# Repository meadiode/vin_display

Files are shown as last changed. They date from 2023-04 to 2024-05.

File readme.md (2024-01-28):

# Vintage display module

A series of RP2040 based display modules for 3d-printers using dot-matrix, or 16-segment vintage display ICs.
Intended to be used with [Klipper firmware](https://www.klipper3d.org/).

Currently the following displays were built and tested:

## VinDisplay mdl2416c_x10
Display module features ten MDL2416C which are 4-character 16-segment LED displays.
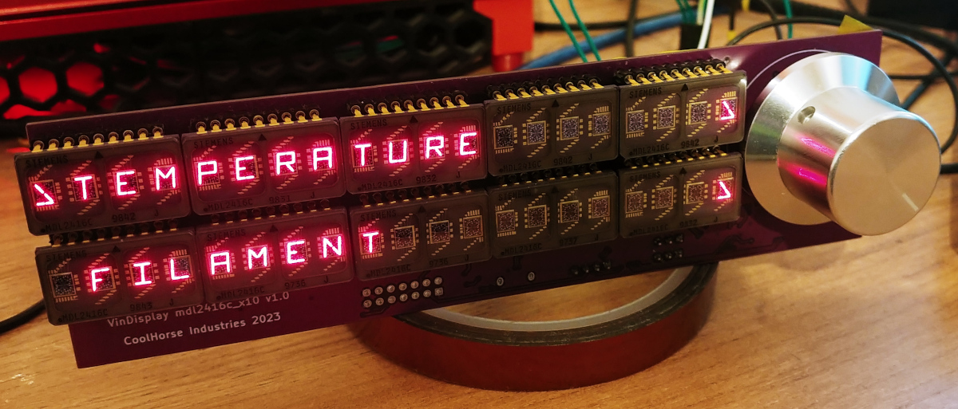
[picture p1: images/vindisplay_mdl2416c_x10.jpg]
VinDisplay mdl2416c_x10


## VinDisplay hdsp2112_x6
Display module features six HDSP-2112 which are 8-character 5x7 LED dot-matrix displays.
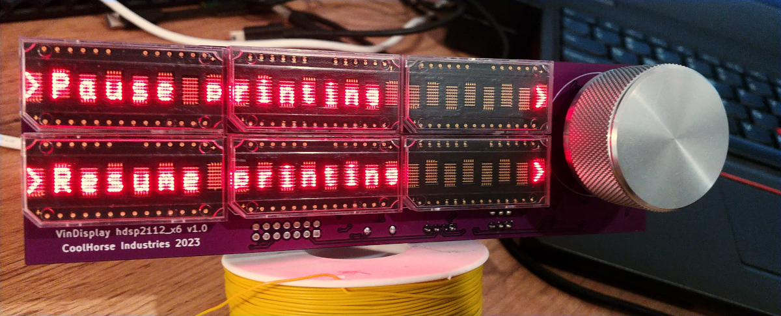
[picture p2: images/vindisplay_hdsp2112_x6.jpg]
VinDisplay hdsp2112_x6


## DemoBoard 1
Simplistic demo-board to evaluate MDL2416C(16-segment LED display), 8 of them are driven by a pico_w. The board just displays current time and date and also prints custom message through a web-interface.
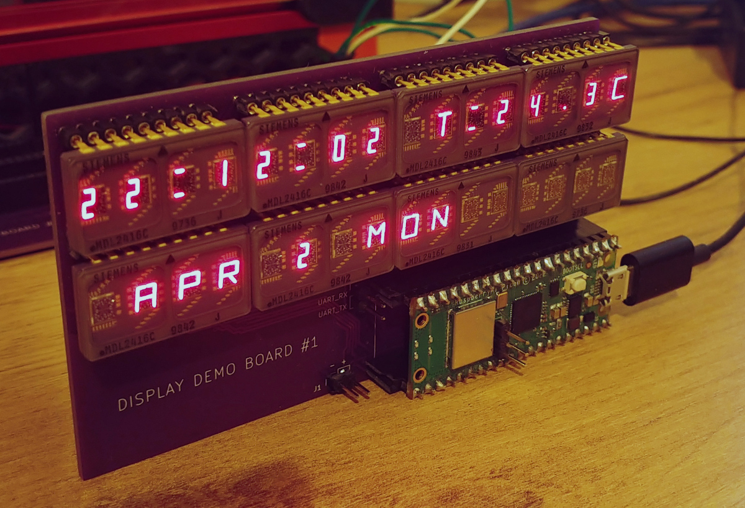
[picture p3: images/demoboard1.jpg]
DemoBoard1


## Building Firmware

### Prerequisites 

Generally, refer to the official [Getting started guide](https://datasheets.raspberrypi.com/pico/getting-started-with-pico.pdf)

You'll need to have:

- ARM embedded gcc toolchain
- GDB (gdb-multiarch)
- Pico SDK
- Pico probe
- FreeRTOS
- Pico OpenOCD

The following environment constants should be defined:
```
PICO_SDK_PATH=/* Path to the root of pico-sdk directory */
FREERTOS_KERNEL_PATH=/* Path to the root of FreeRTOS kernel directory */
```

### Configuring and building

```
cd src
mkdir build
cd build
cmake -DCMAKE_BUILD_TYPE=Debug ..

make
```

### Running and debugging

Connect the picoprobe to the target pico_w board according to the "getting started guide", then run the following:

```
cd [Pico OpenOCD source directory]
sudo src/openocd -f interface/picoprobe.cfg -f target/rp2040.cfg -s tcl
```
It should start a GDB server on the default port 3333.

To flash and run/debug the firmware navigate to the project's directory and run the following: 
```
cd build
gdb-multiarch ./<binary name>.elf
```
Once GDB started:
```
target remote :3333
load
monitor init reset
cont
```

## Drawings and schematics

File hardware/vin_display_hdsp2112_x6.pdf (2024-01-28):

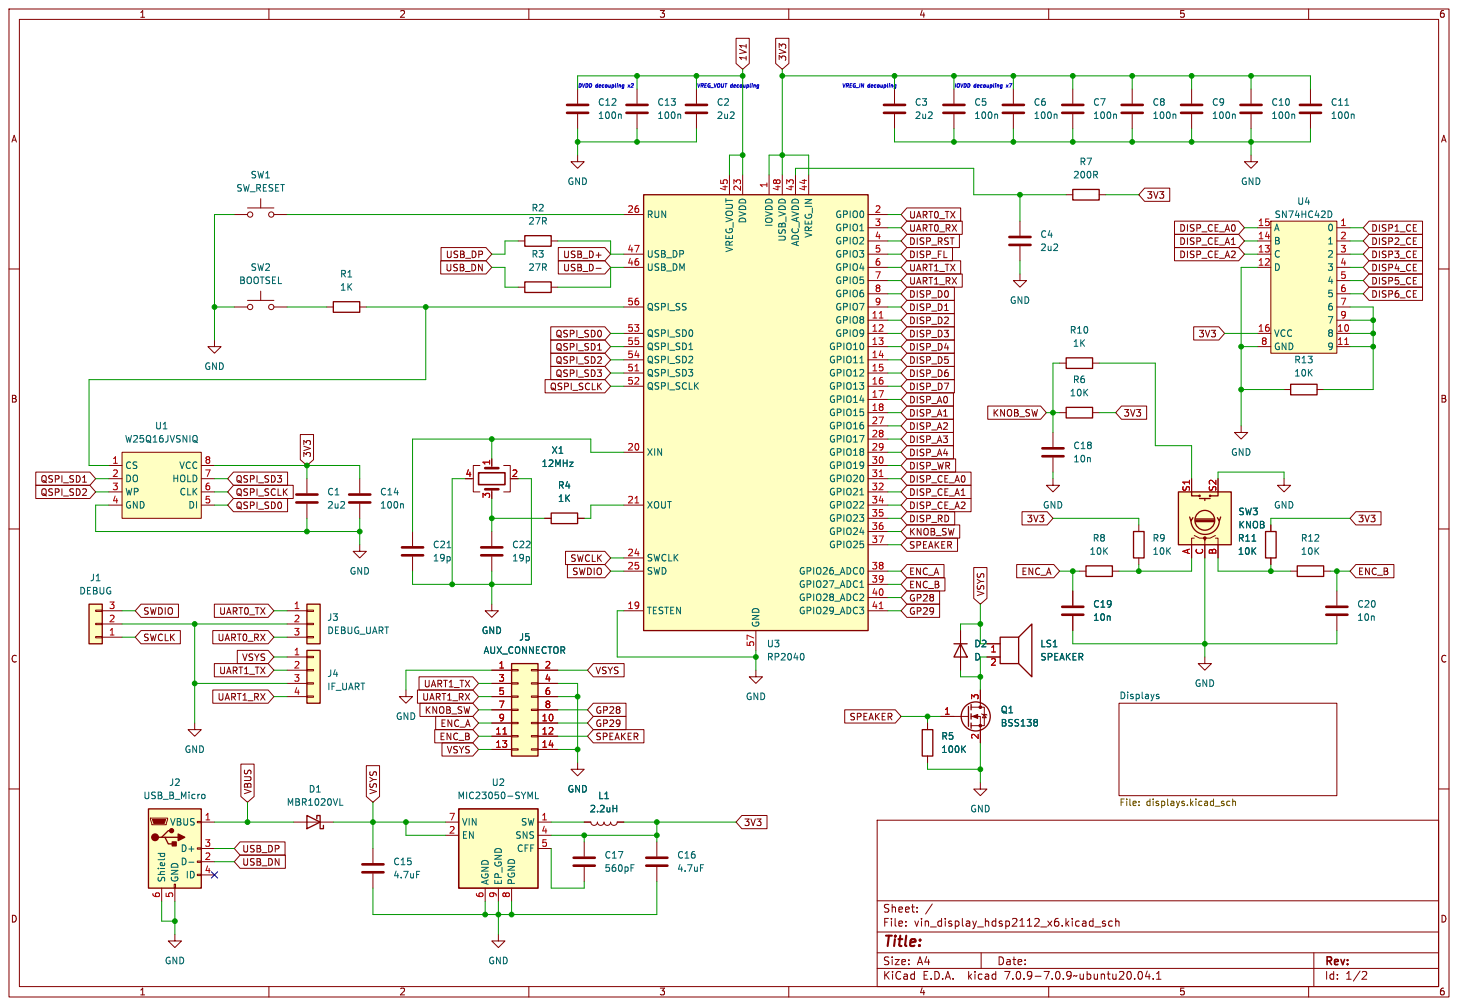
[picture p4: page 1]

1 GPIO8 11 GPIO9 12 GPIO10 13 GPIO11 14 GPIO12 15 GPIO13 16 GPIO14 17 GPIO15 18 TESTEN 19 GPIO0 2 XIN 20 XOUT 21 DVDD 23 SWCLK 24 SWD 25 RUN 26 GPIO16 27 GPIO17 28 GPIO18 29 GPIO1 3 GPIO19 30 GPIO20 31 GPIO21 32 GPIO22 34 GPIO23 35 GPIO24 36 GPIO25 37 GPIO26_ADC0 38 GPIO27_ADC1 39 GPIO2 4 GPIO28_ADC2 40 GPIO29_ADC3 41 ADC_AVDD 43 VREG_IN 44 VREG_VOUT 45 USB_DM 46 USB_DP 47 USB_VDD 48 GPIO3 5 QSPI_SD3 51 QSPI_SCLK 52 QSPI_SD0 53 QSPI_SD2 54 QSPI_SD1 55 QSPI_SS 56 GND 57 GPIO4 6 GPIO5 7 GPIO6 8 GPIO7 9 U3 RP2040 GND GND GND

9 SW 1 EN 2 SNS 4 CFF 5 AGND

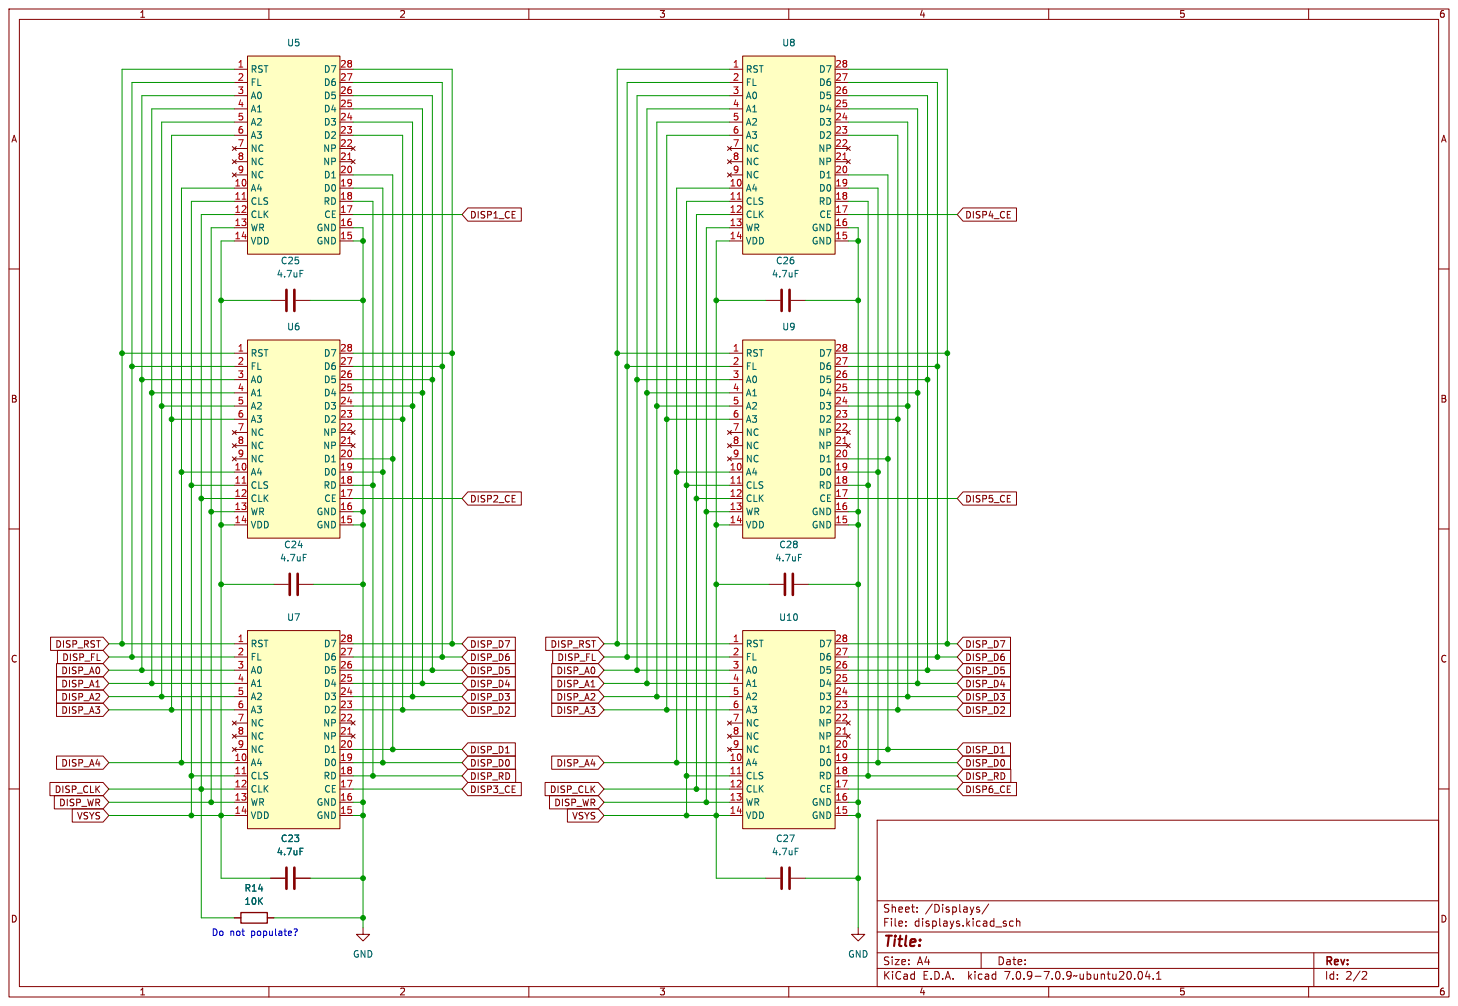
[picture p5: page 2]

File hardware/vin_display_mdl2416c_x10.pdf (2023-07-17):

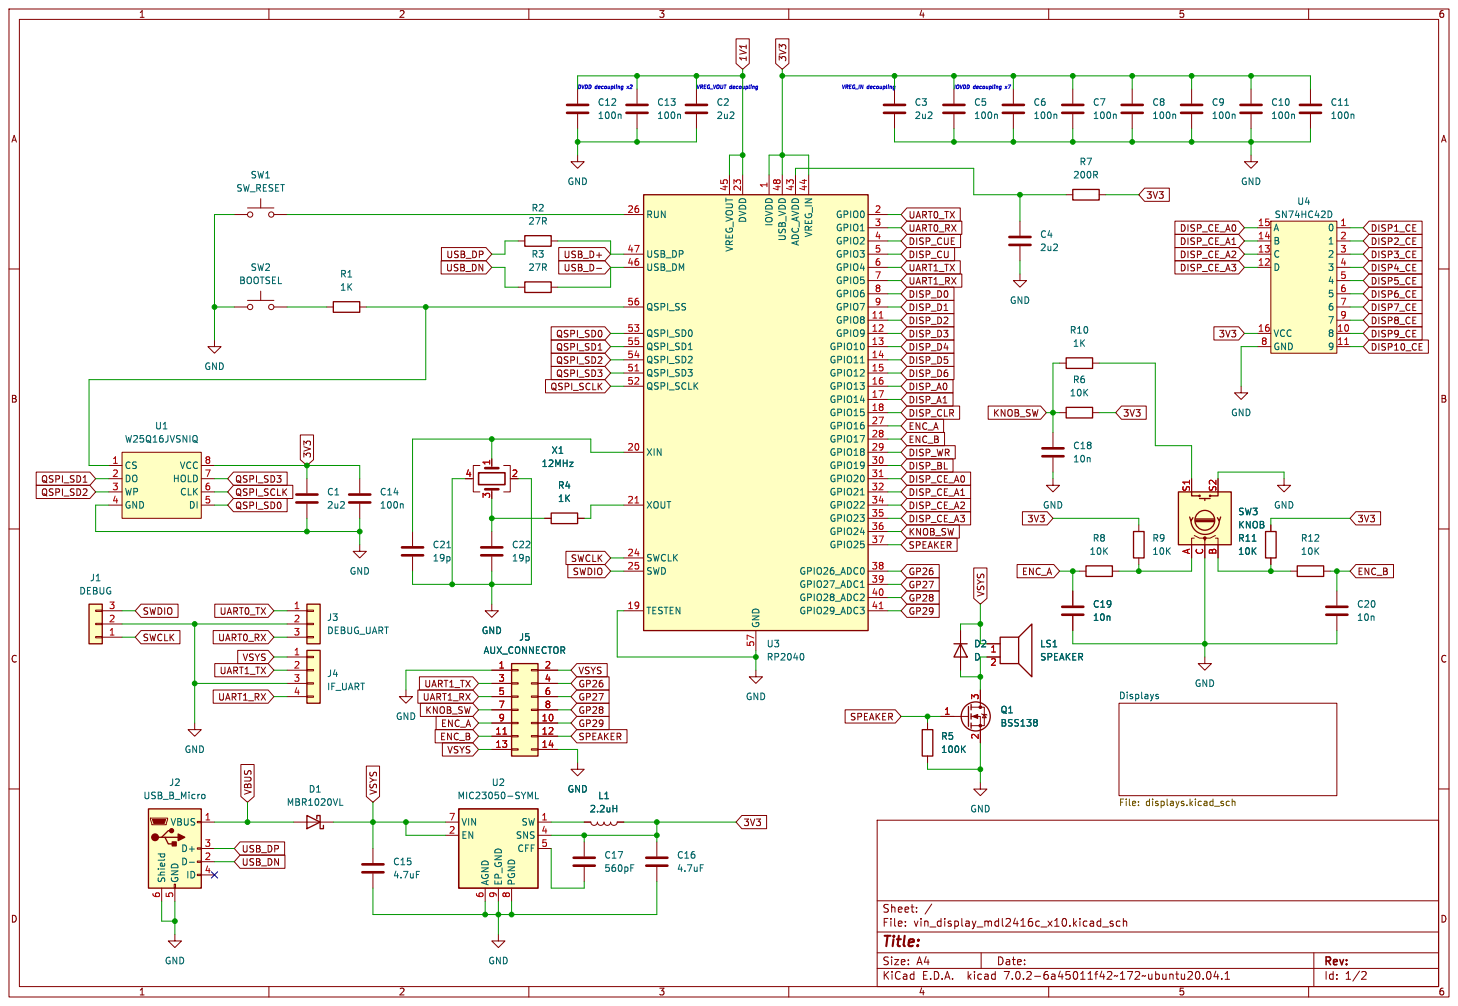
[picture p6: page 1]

1 GPIO8 11 GPIO9 12 GPIO10 13 GPIO11 14 GPIO12 15 GPIO13 16 GPIO14 17 GPIO15 18 TESTEN 19 GPIO0 2 XIN 20 XOUT 21 DVDD 23 SWCLK 24 SWD 25 RUN 26 GPIO16 27 GPIO17 28 GPIO18 29 GPIO1 3 GPIO19 30 GPIO20 31 GPIO21 32 GPIO22 34 GPIO23 35 GPIO24 36 GPIO25 37 GPIO26_ADC0 38 GPIO27_ADC1 39 GPIO2 4 GPIO28_ADC2 40 GPIO29_ADC3 41 ADC_AVDD 43 VREG_IN 44 VREG_VOUT 45 USB_DM 46 USB_DP 47 USB_VDD 48 GPIO3 5 QSPI_SD3 51 QSPI_SCLK 52 QSPI_SD0 53 QSPI_SD2 54 QSPI_SD1 55 QSPI_SS 56 GND 57 GPIO4 6 GPIO5 7 GPIO6 8 GPIO7 9 U3 RP2040 AC

9 SW 1 EN 2 SNS 4 CFF 5 AGND

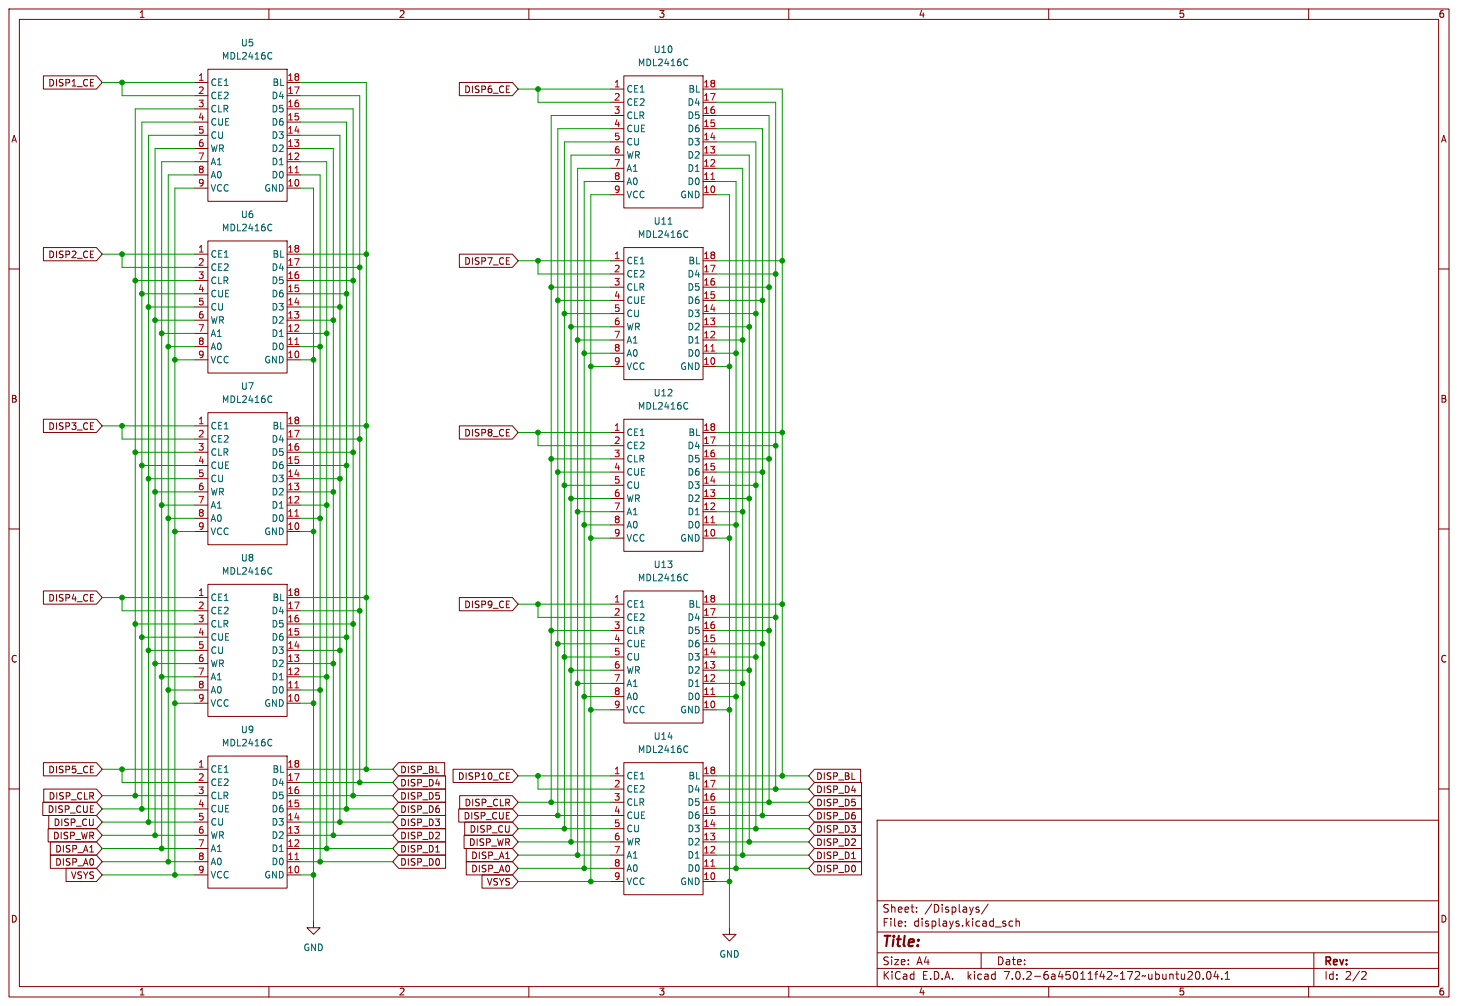
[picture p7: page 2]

Id: 2/2 Title: File: displays.kicad_sch Sheet: /Displays/

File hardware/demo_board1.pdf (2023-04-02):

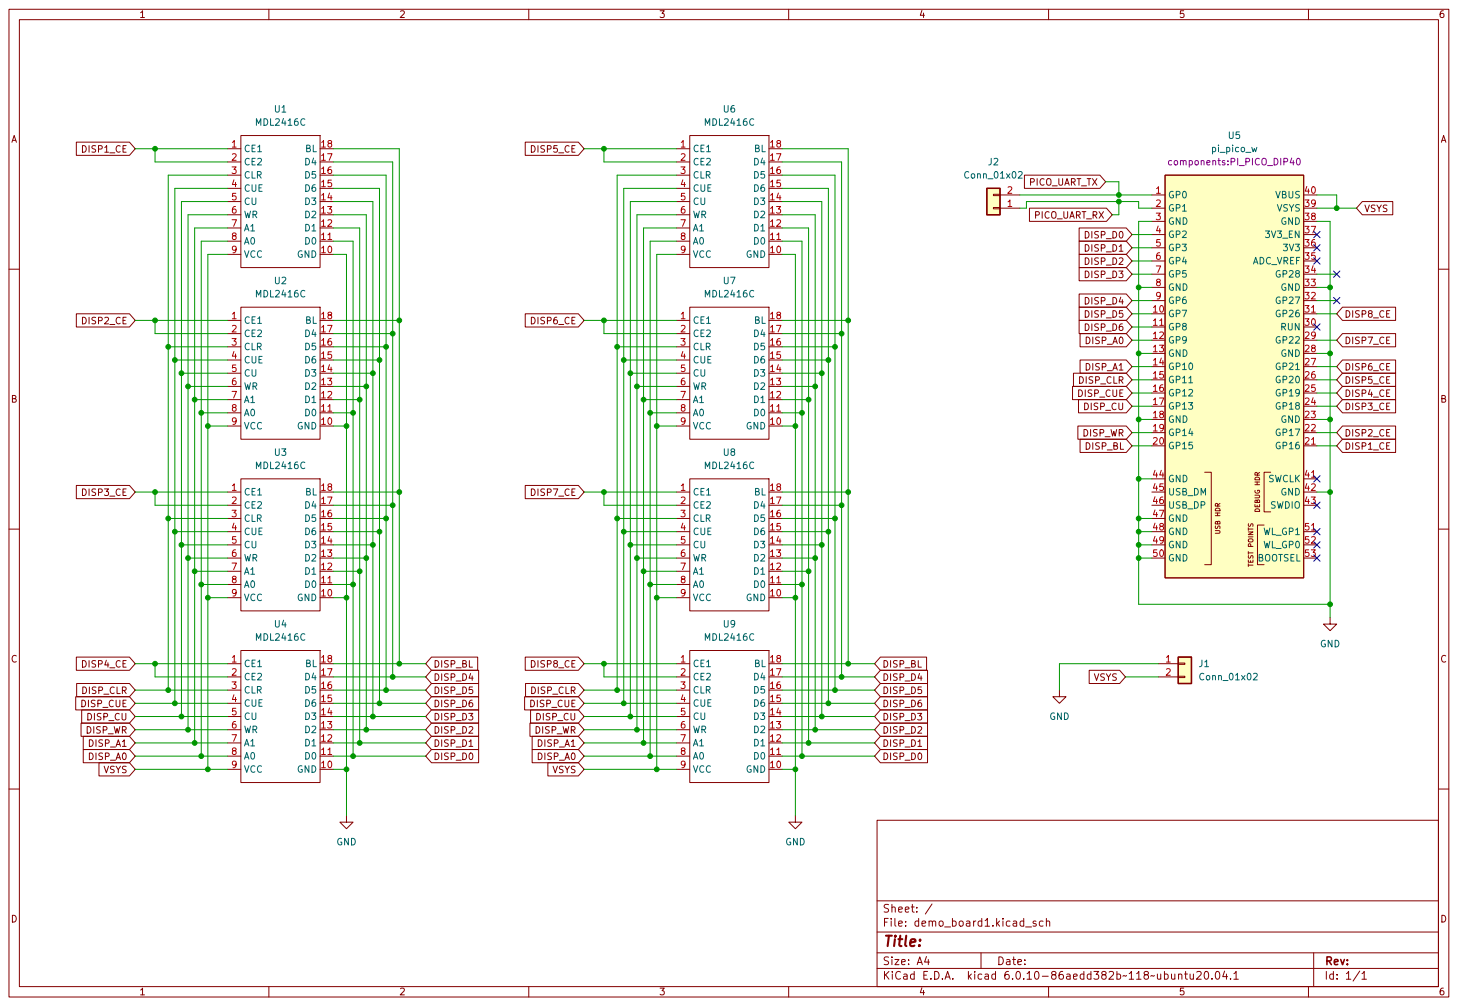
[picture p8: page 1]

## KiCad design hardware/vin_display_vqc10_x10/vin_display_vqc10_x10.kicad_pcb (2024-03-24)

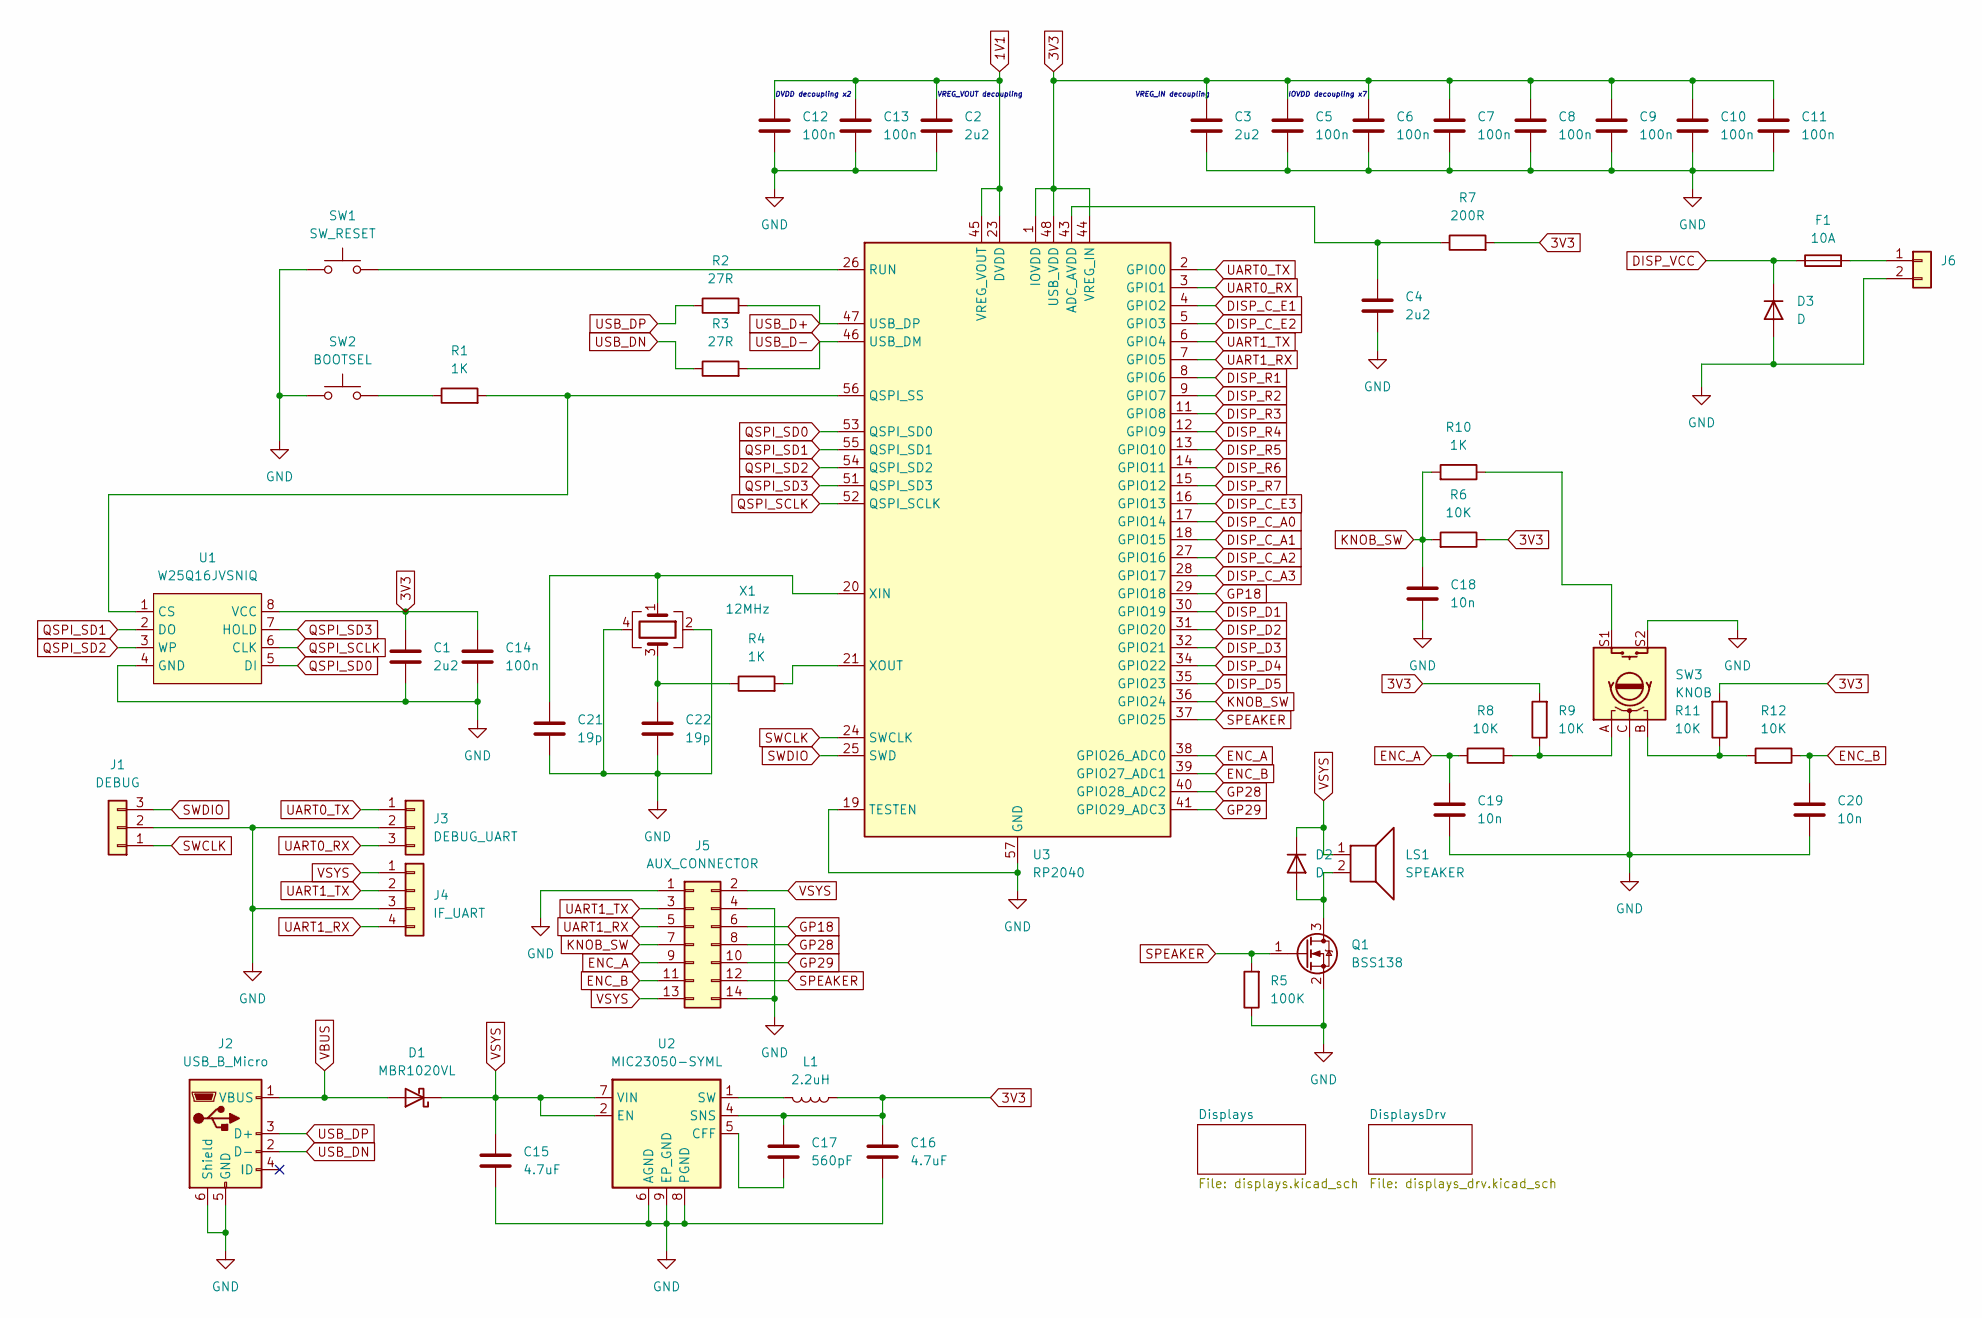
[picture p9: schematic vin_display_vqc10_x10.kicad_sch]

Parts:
C1, C2, C3, C4: 2u2; C_0603_1608Metric
C5, C6, C7, C8, C9, C10, C11, C12, C13, C14: 100n; C_0603_1608Metric
C15, C16: 4.7uF; C_0603_1608Metric
C17: 560pF; C_0603_1608Metric
C18, C19, C20: 10n; C_0603_1608Metric
C21, C22: 19p; C_0603_1608Metric
D1: MBR1020VL; D_SOD-123F
D2: D; D_SOD-123
D3: D; Diode_TO252
F1: 10A; Fuse_2410
J1: DEBUG; JST_EH_B3B-EH-A_1x03_P2.50mm_Vertical
J2: USB_B_Micro; GCT_USB3140
J3: DEBUG_UART; JST_EH_B3B-EH-A_1x03_P2.50mm_Vertical
J4: IF_UART; JST_EH_B4B-EH-A_1x04_P2.50mm_Vertical
J5: AUX_CONNECTOR; IDC-Header_2x07_P2.54mm_Vertical
J6: Conn_01x02; Conn_2x3_96
L1: 2.2uH; Inductor_0806
LS1: SPEAKER; BUZZER_CMT-8504
Q1: BSS138; SOT-23
R1, R4, R10: 1K; R_0603_1608Metric
R2, R3: 27R; R_0603_1608Metric
R5: 100K; R_0603_1608Metric
R6, R8, R9, R11, R12: 10K; R_0603_1608Metric
R7: 200R; R_0603_1608Metric
SW1: SW_RESET; TS18_TACTILE_SWITCH
SW2: BOOTSEL; TS18_TACTILE_SWITCH
SW3: KNOB; PEC11H_Encoder
U1: W25Q16JVSNIQ; SOIC8_150mil
U2: MIC23050-SYML; Micrel_MLF-8-1EP_2x2mm_P0.5mm_EP0.6x1.2mm
U3: RP2040; QFN-56-1EP_7x7mm_P0.4mm_EP3.2x3.2mm
X1: 12MHz; Crystal_SMD_Abracon_ABM8AIG-4Pin_3.2x2.5mm

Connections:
1V1: C2.1, C12.1, C13.1, U3.23 (DVDD), U3.45 (VREG_VOUT), U3.50 (DVDD)
3V3: C1.1, C3.1, C5.1, C6.1, C7.1, C8.1, C9.1, C10.1, C11.1, C14.1, C16.1, C17.1, L1.1, R6.1, R7.2, R9.2, R11.2, U1.8 (VCC), U2.4 (SNS), U3.1 (IOVDD), U3.10 (IOVDD), U3.22 (IOVDD), U3.33 (IOVDD), U3.42 (IOVDD), U3.44 (VREG_IN), U3.48 (USB_VDD), U3.49 (IOVDD); also elsewhere on the board
DISP_C_A0: U3.17 (GPIO14); also elsewhere on the board
DISP_C_A1: U3.18 (GPIO15); also elsewhere on the board
DISP_C_A2: U3.27 (GPIO16); also elsewhere on the board
DISP_C_A3: U3.28 (GPIO17); also elsewhere on the board
DISP_C_E1: U3.4 (GPIO2); also elsewhere on the board
DISP_C_E2: U3.5 (GPIO3); also elsewhere on the board
DISP_C_E3: U3.16 (GPIO13); also elsewhere on the board
DISP_D1: U3.30 (GPIO19); also elsewhere on the board
DISP_D2: U3.31 (GPIO20); also elsewhere on the board
DISP_D3: U3.32 (GPIO21); also elsewhere on the board
DISP_D4: U3.34 (GPIO22); also elsewhere on the board
DISP_D5: U3.35 (GPIO23); also elsewhere on the board
DISP_R1: U3.8 (GPIO6); also elsewhere on the board
DISP_R2: U3.9 (GPIO7); also elsewhere on the board
DISP_R3: U3.11 (GPIO8); also elsewhere on the board
DISP_R4: U3.12 (GPIO9); also elsewhere on the board
DISP_R5: U3.13 (GPIO10); also elsewhere on the board
DISP_R6: U3.14 (GPIO11); also elsewhere on the board
DISP_R7: U3.15 (GPIO12); also elsewhere on the board
DISP_VCC: D3.1 (K), F1.1; also elsewhere on the board
ENC_A: C19.1, J5.9, R8.1, U3.38 (GPIO26_ADC0)
ENC_B: C20.1, J5.11, R12.1, U3.39 (GPIO27_ADC1)
GND: C1.2, C2.2, C3.2, C4.2, C5.2, C6.2, C7.2, C8.2, C9.2, C10.2, C11.2, C12.2, C13.2, C14.2, C15.2, C16.2, C18.2, C19.2, C20.2, C21.2, C22.2, D3.2 (A), J1.2, J2.5 (GND), J2.6 (Shield), J3.2, J4.3, J5.1, J5.4, J5.14, J6.2, Q1.2 (S), R5.1, SW1.1, SW2.1, SW3.C, SW3.S2, U1.4 (GND), U2.6 (AGND), U2.8 (PGND), U2.9 (EP_GND), U3.19 (TESTEN), U3.57 (GND), X1.2, X1.4; also elsewhere on the board
GP18: J5.6, U3.29 (GPIO18)
GP28: J5.8, U3.40 (GPIO28_ADC2)
GP29: J5.10, U3.41 (GPIO29_ADC3)
KNOB_SW: C18.1, J5.7, R6.2, R10.2, U3.36 (GPIO24)
unnamed: C22.1, R4.1, X1.3
unnamed: D2.2 (A), LS1.2, Q1.3 (D)
unnamed: F1.2, J6.1
unnamed: R1.1, SW2.2
unnamed: R8.2, R9.1, SW3.A
unnamed: R10.1, SW3.S1
unnamed: R11.1, R12.2, SW3.B
unnamed: R1.2, U1.1 (CS), U3.56 (QSPI_SS)
unnamed: C17.2, U2.5 (CFF)
unnamed: L1.2, U2.1 (SW)
unnamed: C4.1, R7.1, U3.43 (ADC_AVDD)
unnamed: SW1.2, U3.26 (RUN)
unnamed: C21.1, U3.20 (XIN), X1.1
unnamed: R4.2, U3.21 (XOUT)
QSPI_SCLK: U1.6 (CLK), U3.52 (QSPI_SCLK)
QSPI_SD0: U1.5 (DI), U3.53 (QSPI_SD0)
QSPI_SD1: U1.2 (DO), U3.55 (QSPI_SD1)
QSPI_SD2: U1.3 (WP), U3.54 (QSPI_SD2)
QSPI_SD3: U1.7 (HOLD), U3.51 (QSPI_SD3)
SPEAKER: J5.12, Q1.1 (G), R5.2, U3.37 (GPIO25)
SWCLK: J1.1, U3.24 (SWCLK)
SWDIO: J1.3, U3.25 (SWD)
UART0_RX: J3.3, U3.3 (GPIO1)
UART0_TX: J3.1, U3.2 (GPIO0)
UART1_RX: J4.4, J5.5, U3.7 (GPIO5)
UART1_TX: J4.2, J5.3, U3.6 (GPIO4)
USB_D+: R2.2, U3.47 (USB_DP)
USB_D-: R3.2, U3.46 (USB_DM)
USB_DN: J2.2 (D-), R3.1
USB_DP: J2.3 (D+), R2.1
VBUS: D1.2 (A), J2.1 (VBUS)
VSYS: C15.1, D1.1 (K), D2.1 (K), J4.1, J5.2, J5.13, LS1.1, U2.2 (EN), U2.7 (VIN)

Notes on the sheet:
IOVDD decoupling x7
DVDD decoupling x2
VREG_IN decoupling
VREG_VOUT decoupling

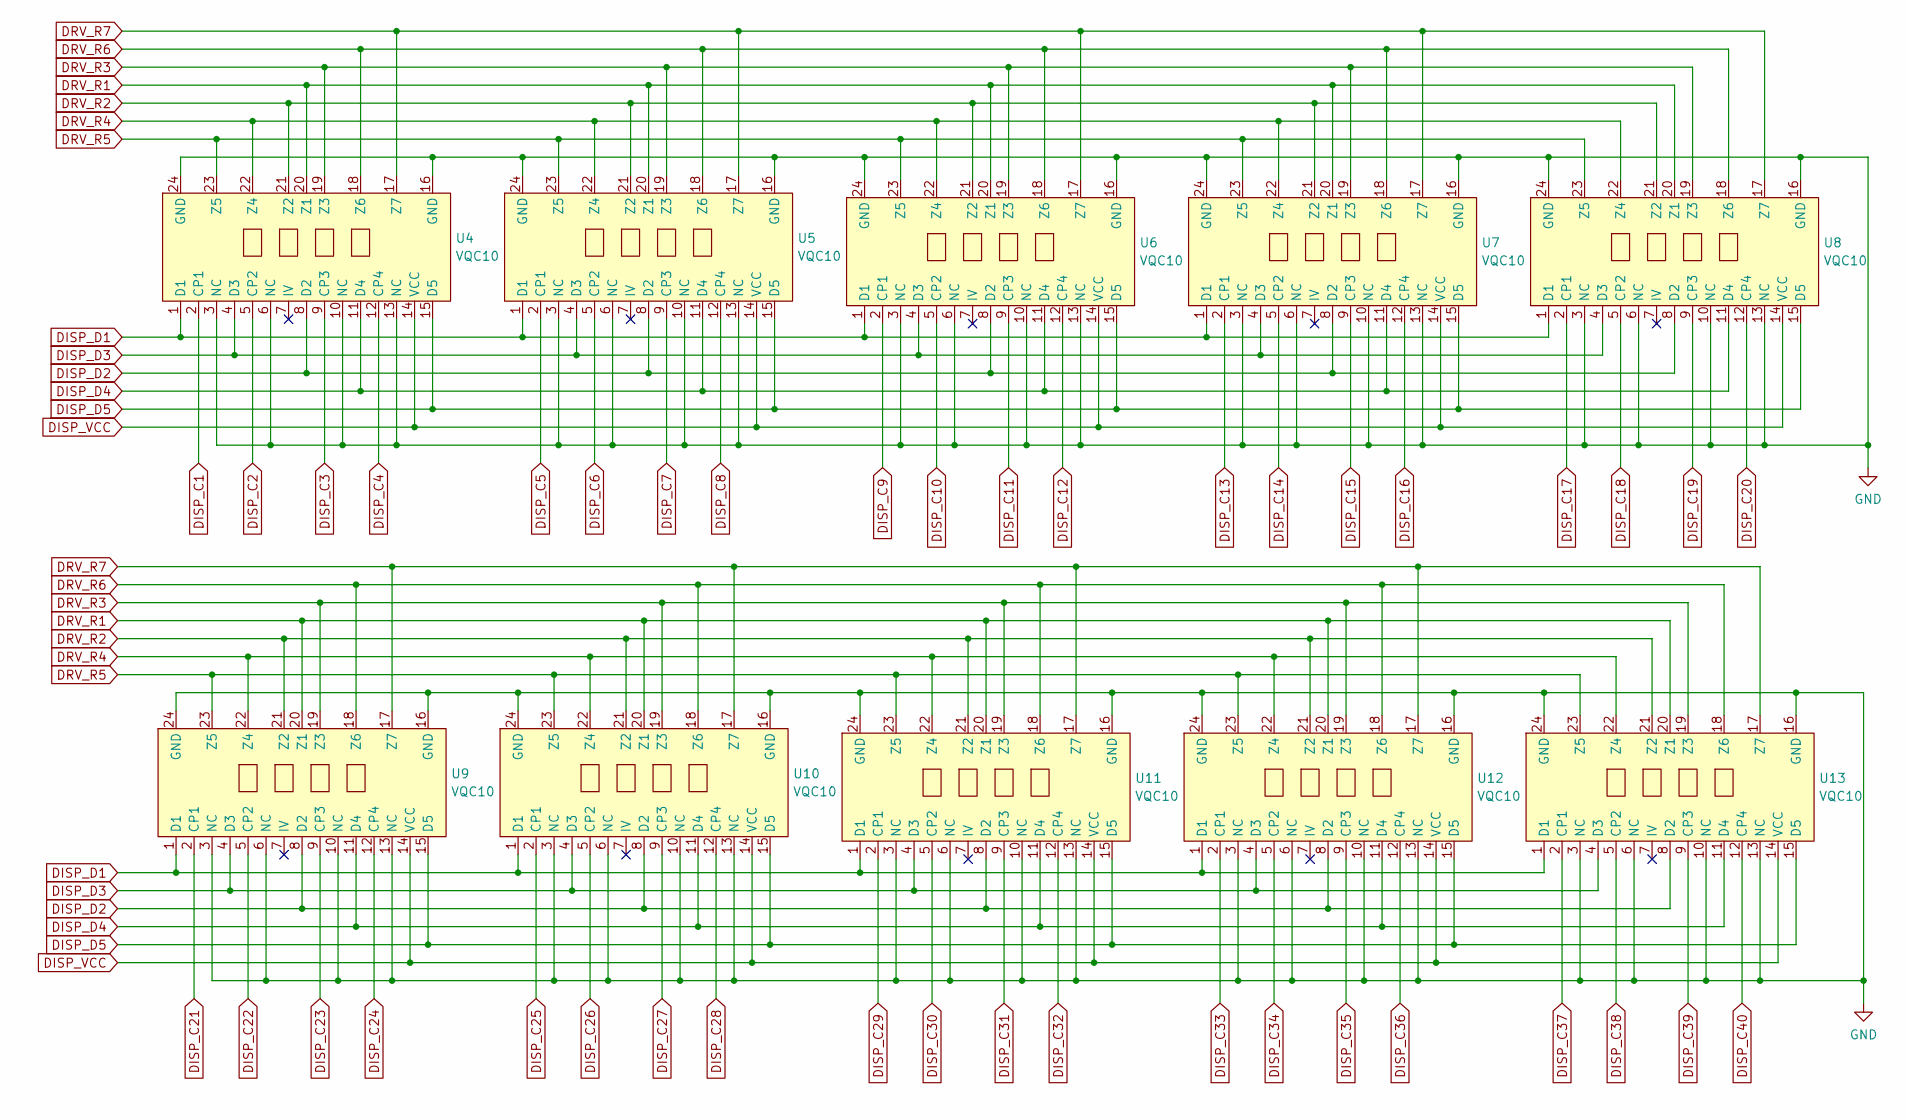
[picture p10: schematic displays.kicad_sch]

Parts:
U4, U5, U6, U7, U8, U9, U10, U11, U12, U13: VQC10

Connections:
DISP_C1: U4.2 (CP1); also elsewhere on the board
DISP_C2: U4.5 (CP2); also elsewhere on the board
DISP_C3: U4.9 (CP3); also elsewhere on the board
DISP_C4: U4.12 (CP4); also elsewhere on the board
DISP_C5: U5.2 (CP1); also elsewhere on the board
DISP_C6: U5.5 (CP2); also elsewhere on the board
DISP_C7: U5.9 (CP3); also elsewhere on the board
DISP_C8: U5.12 (CP4); also elsewhere on the board
DISP_C9: U6.2 (CP1); also elsewhere on the board
DISP_C10: U6.5 (CP2); also elsewhere on the board
DISP_C11: U6.9 (CP3); also elsewhere on the board
DISP_C12: U6.12 (CP4); also elsewhere on the board
DISP_C13: U7.2 (CP1); also elsewhere on the board
DISP_C14: U7.5 (CP2); also elsewhere on the board
DISP_C15: U7.9 (CP3); also elsewhere on the board
DISP_C16: U7.12 (CP4); also elsewhere on the board
DISP_C17: U8.2 (CP1); also elsewhere on the board
DISP_C18: U8.5 (CP2); also elsewhere on the board
DISP_C19: U8.9 (CP3); also elsewhere on the board
DISP_C20: U8.12 (CP4); also elsewhere on the board
DISP_C21: U9.2 (CP1); also elsewhere on the board
DISP_C22: U9.5 (CP2); also elsewhere on the board
DISP_C23: U9.9 (CP3); also elsewhere on the board
DISP_C24: U9.12 (CP4); also elsewhere on the board
DISP_C25: U10.2 (CP1); also elsewhere on the board
DISP_C26: U10.5 (CP2); also elsewhere on the board
DISP_C27: U10.9 (CP3); also elsewhere on the board
DISP_C28: U10.12 (CP4); also elsewhere on the board
DISP_C29: U11.2 (CP1); also elsewhere on the board
DISP_C30: U11.5 (CP2); also elsewhere on the board
DISP_C31: U11.9 (CP3); also elsewhere on the board
DISP_C32: U11.12 (CP4); also elsewhere on the board
DISP_C33: U12.2 (CP1); also elsewhere on the board
DISP_C34: U12.5 (CP2); also elsewhere on the board
DISP_C35: U12.9 (CP3); also elsewhere on the board
DISP_C36: U12.12 (CP4); also elsewhere on the board
DISP_C37: U13.2 (CP1); also elsewhere on the board
DISP_C38: U13.5 (CP2); also elsewhere on the board
DISP_C39: U13.9 (CP3); also elsewhere on the board
DISP_C40: U13.12 (CP4); also elsewhere on the board
DISP_D1: U4.1 (D1), U5.1 (D1), U6.1 (D1), U7.1 (D1), U8.1 (D1), U9.1 (D1), U10.1 (D1), U11.1 (D1), U12.1 (D1), U13.1 (D1); also elsewhere on the board
DISP_D2: U4.8 (D2), U5.8 (D2), U6.8 (D2), U7.8 (D2), U8.8 (D2), U9.8 (D2), U10.8 (D2), U11.8 (D2), U12.8 (D2), U13.8 (D2); also elsewhere on the board
DISP_D3: U4.4 (D3), U5.4 (D3), U6.4 (D3), U7.4 (D3), U8.4 (D3), U9.4 (D3), U10.4 (D3), U11.4 (D3), U12.4 (D3), U13.4 (D3); also elsewhere on the board
DISP_D4: U4.11 (D4), U5.11 (D4), U6.11 (D4), U7.11 (D4), U8.11 (D4), U9.11 (D4), U10.11 (D4), U11.11 (D4), U12.11 (D4), U13.11 (D4); also elsewhere on the board
DISP_D5: U4.15 (D5), U5.15 (D5), U6.15 (D5), U7.15 (D5), U8.15 (D5), U9.15 (D5), U10.15 (D5), U11.15 (D5), U12.15 (D5), U13.15 (D5); also elsewhere on the board
DISP_VCC: U4.14 (VCC), U5.14 (VCC), U6.14 (VCC), U7.14 (VCC), U8.14 (VCC), U9.14 (VCC), U10.14 (VCC), U11.14 (VCC), U12.14 (VCC), U13.14 (VCC); also elsewhere on the board
DRV_R1: U4.20 (Z1), U5.20 (Z1), U6.20 (Z1), U7.20 (Z1), U8.20 (Z1), U9.20 (Z1), U10.20 (Z1), U11.20 (Z1), U12.20 (Z1), U13.20 (Z1); also elsewhere on the board
DRV_R2: U4.21 (Z2), U5.21 (Z2), U6.21 (Z2), U7.21 (Z2), U8.21 (Z2), U9.21 (Z2), U10.21 (Z2), U11.21 (Z2), U12.21 (Z2), U13.21 (Z2); also elsewhere on the board
DRV_R3: U4.19 (Z3), U5.19 (Z3), U6.19 (Z3), U7.19 (Z3), U8.19 (Z3), U9.19 (Z3), U10.19 (Z3), U11.19 (Z3), U12.19 (Z3), U13.19 (Z3); also elsewhere on the board
DRV_R4: U4.22 (Z4), U5.22 (Z4), U6.22 (Z4), U7.22 (Z4), U8.22 (Z4), U9.22 (Z4), U10.22 (Z4), U11.22 (Z4), U12.22 (Z4), U13.22 (Z4); also elsewhere on the board
DRV_R5: U4.23 (Z5), U5.23 (Z5), U6.23 (Z5), U7.23 (Z5), U8.23 (Z5), U9.23 (Z5), U10.23 (Z5), U11.23 (Z5), U12.23 (Z5), U13.23 (Z5); also elsewhere on the board
DRV_R6: U4.18 (Z6), U5.18 (Z6), U6.18 (Z6), U7.18 (Z6), U8.18 (Z6), U9.18 (Z6), U10.18 (Z6), U11.18 (Z6), U12.18 (Z6), U13.18 (Z6); also elsewhere on the board
DRV_R7: U4.17 (Z7), U5.17 (Z7), U6.17 (Z7), U7.17 (Z7), U8.17 (Z7), U9.17 (Z7), U10.17 (Z7), U11.17 (Z7), U12.17 (Z7), U13.17 (Z7); also elsewhere on the board
GND: U4.3 (NC), U4.6 (NC), U4.10 (NC), U4.13 (NC), U4.16 (GND), U4.24 (GND), U5.3 (NC), U5.6 (NC), U5.10 (NC), U5.13 (NC), U5.16 (GND), U5.24 (GND), U6.3 (NC), U6.6 (NC), U6.10 (NC), U6.13 (NC), U6.16 (GND), U6.24 (GND), U7.3 (NC), U7.6 (NC), U7.10 (NC), U7.13 (NC), U7.16 (GND), U7.24 (GND), U8.3 (NC), U8.6 (NC), U8.10 (NC), U8.13 (NC), U8.16 (GND), U8.24 (GND), U9.3 (NC), U9.6 (NC), U9.10 (NC), U9.13 (NC), U9.16 (GND), U9.24 (GND), U10.3 (NC), U10.6 (NC), U10.10 (NC), U10.13 (NC), U10.16 (GND), U10.24 (GND), U11.3 (NC), U11.6 (NC), U11.10 (NC), U11.13 (NC), U11.16 (GND), U11.24 (GND), U12.3 (NC), U12.6 (NC), U12.10 (NC), U12.13 (NC), U12.16 (GND), U12.24 (GND), U13.3 (NC), U13.6 (NC), U13.10 (NC), U13.13 (NC), U13.16 (GND), U13.24 (GND); also elsewhere on the board

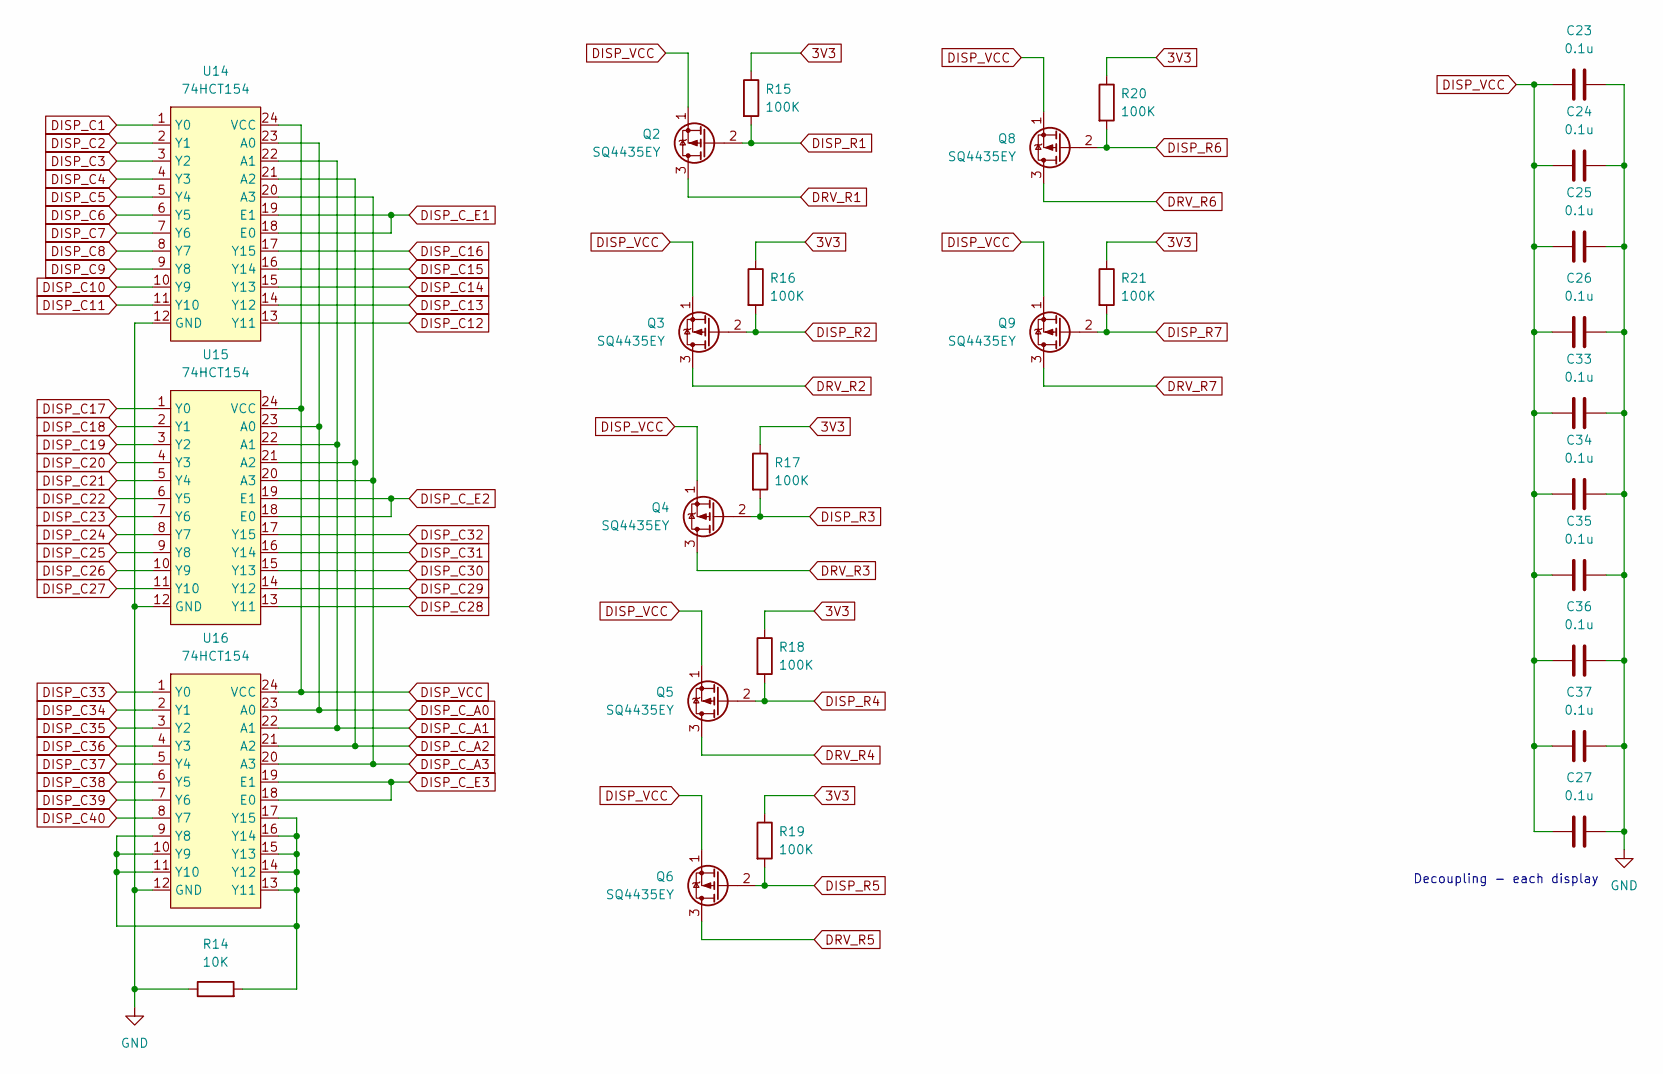
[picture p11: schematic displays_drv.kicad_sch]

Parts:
C23, C24, C25, C26, C27, C33, C34, C35, C36, C37: 0.1u; C_0603_1608Metric
Q2, Q3, Q4, Q5, Q6, Q8, Q9: SQ4435EY; SO8_MOSFET_S3G1D4
R14: 10K; C_0603_1608Metric
R15, R16, R17, R18, R19, R20, R21: 100K; R_0603_1608Metric
U14, U15, U16: 74HCT154; TSSOP-24_4.4x7.8mm_P0.65mm

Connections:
3V3: R15.1, R16.1, R17.1, R18.1, R19.1, R20.1, R21.1; also elsewhere on the board
DISP_C1: U14.1 (Y0); also elsewhere on the board
DISP_C2: U14.2 (Y1); also elsewhere on the board
DISP_C3: U14.3 (Y2); also elsewhere on the board
DISP_C4: U14.4 (Y3); also elsewhere on the board
DISP_C5: U14.5 (Y4); also elsewhere on the board
DISP_C6: U14.6 (Y5); also elsewhere on the board
DISP_C7: U14.7 (Y6); also elsewhere on the board
DISP_C8: U14.8 (Y7); also elsewhere on the board
DISP_C9: U14.9 (Y8); also elsewhere on the board
DISP_C10: U14.10 (Y9); also elsewhere on the board
DISP_C11: U14.11 (Y10); also elsewhere on the board
DISP_C12: U14.13 (Y11); also elsewhere on the board
DISP_C13: U14.14 (Y12); also elsewhere on the board
DISP_C14: U14.15 (Y13); also elsewhere on the board
DISP_C15: U14.16 (Y14); also elsewhere on the board
DISP_C16: U14.17 (Y15); also elsewhere on the board
DISP_C17: U15.1 (Y0); also elsewhere on the board
DISP_C18: U15.2 (Y1); also elsewhere on the board
DISP_C19: U15.3 (Y2); also elsewhere on the board
DISP_C20: U15.4 (Y3); also elsewhere on the board
DISP_C21: U15.5 (Y4); also elsewhere on the board
DISP_C22: U15.6 (Y5); also elsewhere on the board
DISP_C23: U15.7 (Y6); also elsewhere on the board
DISP_C24: U15.8 (Y7); also elsewhere on the board
DISP_C25: U15.9 (Y8); also elsewhere on the board
DISP_C26: U15.10 (Y9); also elsewhere on the board
DISP_C27: U15.11 (Y10); also elsewhere on the board
DISP_C28: U15.13 (Y11); also elsewhere on the board
DISP_C29: U15.14 (Y12); also elsewhere on the board
DISP_C30: U15.15 (Y13); also elsewhere on the board
DISP_C31: U15.16 (Y14); also elsewhere on the board
DISP_C32: U15.17 (Y15); also elsewhere on the board
DISP_C33: U16.1 (Y0); also elsewhere on the board
DISP_C34: U16.2 (Y1); also elsewhere on the board
DISP_C35: U16.3 (Y2); also elsewhere on the board
DISP_C36: U16.4 (Y3); also elsewhere on the board
DISP_C37: U16.5 (Y4); also elsewhere on the board
DISP_C38: U16.6 (Y5); also elsewhere on the board
DISP_C39: U16.7 (Y6); also elsewhere on the board
DISP_C40: U16.8 (Y7); also elsewhere on the board
DISP_C_A0: U14.23 (A0), U15.23 (A0), U16.23 (A0); also elsewhere on the board
DISP_C_A1: U14.22 (A1), U15.22 (A1), U16.22 (A1); also elsewhere on the board
DISP_C_A2: U14.21 (A2), U15.21 (A2), U16.21 (A2); also elsewhere on the board
DISP_C_A3: U14.20 (A3), U15.20 (A3), U16.20 (A3); also elsewhere on the board
DISP_C_E1: U14.18 (E0), U14.19 (E1); also elsewhere on the board
DISP_C_E2: U15.18 (E0), U15.19 (E1); also elsewhere on the board
DISP_C_E3: U16.18 (E0), U16.19 (E1); also elsewhere on the board
DISP_R1: Q2.2 (G), R15.2; also elsewhere on the board
DISP_R2: Q3.2 (G), R16.2; also elsewhere on the board
DISP_R3: Q4.2 (G), R17.2; also elsewhere on the board
DISP_R4: Q5.2 (G), R18.2; also elsewhere on the board
DISP_R5: Q6.2 (G), R19.2; also elsewhere on the board
DISP_R6: Q8.2 (G), R20.2; also elsewhere on the board
DISP_R7: Q9.2 (G), R21.2; also elsewhere on the board
DISP_VCC: C23.1, C24.1, C25.1, C26.1, C27.1, C33.1, C34.1, C35.1, C36.1, C37.1, Q2.1 (S), Q3.1 (S), Q4.1 (S), Q5.1 (S), Q6.1 (S), Q8.1 (S), Q9.1 (S), U14.24 (VCC), U15.24 (VCC), U16.24 (VCC); also elsewhere on the board
DRV_R1: Q2.3 (D); also elsewhere on the board
DRV_R2: Q3.3 (D); also elsewhere on the board
DRV_R3: Q4.3 (D); also elsewhere on the board
DRV_R4: Q5.3 (D); also elsewhere on the board
DRV_R5: Q6.3 (D); also elsewhere on the board
DRV_R6: Q8.3 (D); also elsewhere on the board
DRV_R7: Q9.3 (D); also elsewhere on the board
GND: C23.2, C24.2, C25.2, C26.2, C27.2, C33.2, C34.2, C35.2, C36.2, C37.2, R14.1, U14.12 (GND), U15.12 (GND), U16.12 (GND); also elsewhere on the board
unnamed: R14.2, U16.9 (Y8), U16.10 (Y9), U16.11 (Y10), U16.13 (Y11), U16.14 (Y12), U16.15 (Y13), U16.16 (Y14), U16.17 (Y15)

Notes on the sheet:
Decoupling - each display

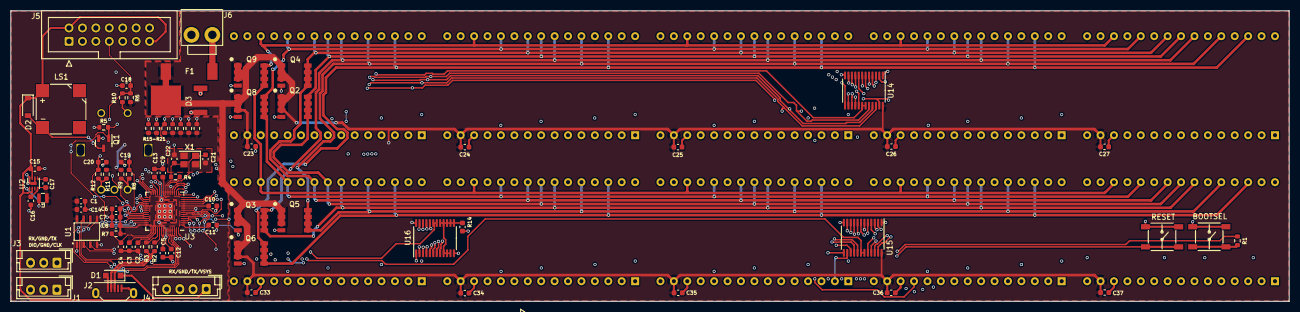
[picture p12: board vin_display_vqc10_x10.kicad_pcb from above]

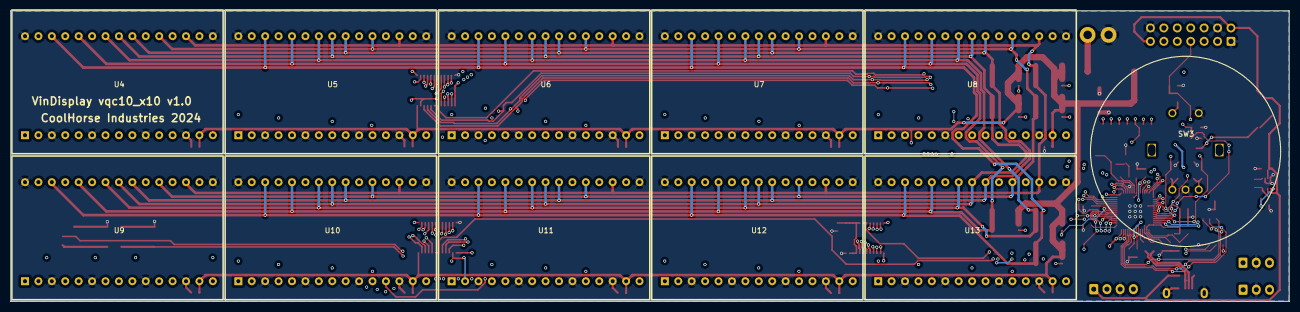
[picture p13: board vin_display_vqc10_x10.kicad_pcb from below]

Board: 4 copper layers, 242.0 x 55.0 mm, 92 parts (11 on the bottom side), 109 nets.

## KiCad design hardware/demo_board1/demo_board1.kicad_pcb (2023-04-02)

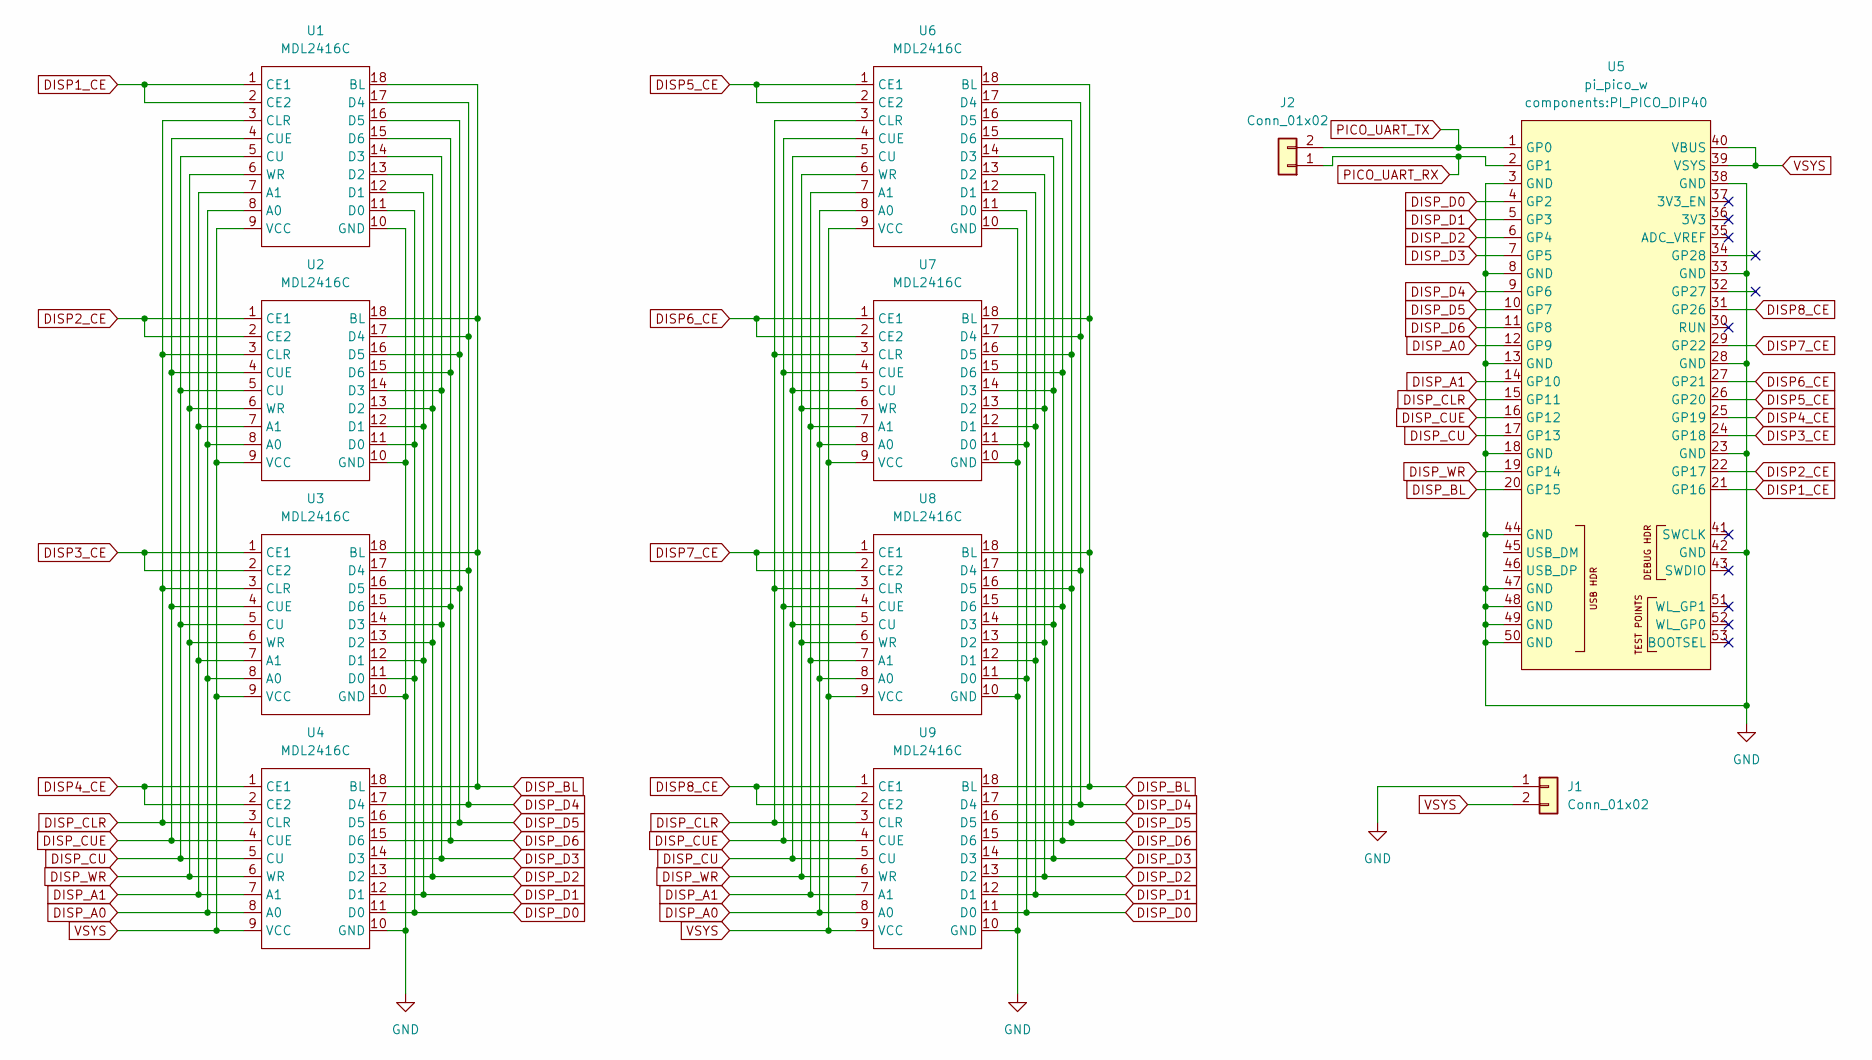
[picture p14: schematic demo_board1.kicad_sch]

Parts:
J1, J2: Conn_01x02; PinHeader_1x02_P2.54mm_Vertical
U1, U2, U3, U4, U6, U7, U8, U9: MDL2416C; DIP-18_W60
U5: pi_pico_w; PI_PICO_DIP40

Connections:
DISP1_CE: U1.1 (CE1), U1.2 (CE2), U5.21 (GP16)
DISP2_CE: U2.1 (CE1), U2.2 (CE2), U5.22 (GP17)
DISP3_CE: U3.1 (CE1), U3.2 (CE2), U5.24 (GP18)
DISP4_CE: U4.1 (CE1), U4.2 (CE2), U5.25 (GP19)
DISP5_CE: U5.26 (GP20), U6.1 (CE1), U6.2 (CE2)
DISP6_CE: U5.27 (GP21), U7.1 (CE1), U7.2 (CE2)
DISP7_CE: U5.29 (GP22), U8.1 (CE1), U8.2 (CE2)
DISP8_CE: U5.31 (GP26), U9.1 (CE1), U9.2 (CE2)
DISP_A0: U1.8 (A0), U2.8 (A0), U3.8 (A0), U4.8 (A0), U5.12 (GP9), U6.8 (A0), U7.8 (A0), U8.8 (A0), U9.8 (A0)
DISP_A1: U1.7 (A1), U2.7 (A1), U3.7 (A1), U4.7 (A1), U5.14 (GP10), U6.7 (A1), U7.7 (A1), U8.7 (A1), U9.7 (A1)
DISP_BL: U1.18 (BL), U2.18 (BL), U3.18 (BL), U4.18 (BL), U5.20 (GP15), U6.18 (BL), U7.18 (BL), U8.18 (BL), U9.18 (BL)
DISP_CLR: U1.3 (CLR), U2.3 (CLR), U3.3 (CLR), U4.3 (CLR), U5.15 (GP11), U6.3 (CLR), U7.3 (CLR), U8.3 (CLR), U9.3 (CLR)
DISP_CU: U1.5 (CU), U2.5 (CU), U3.5 (CU), U4.5 (CU), U5.17 (GP13), U6.5 (CU), U7.5 (CU), U8.5 (CU), U9.5 (CU)
DISP_CUE: U1.4 (CUE), U2.4 (CUE), U3.4 (CUE), U4.4 (CUE), U5.16 (GP12), U6.4 (CUE), U7.4 (CUE), U8.4 (CUE), U9.4 (CUE)
DISP_D0: U1.11 (D0), U2.11 (D0), U3.11 (D0), U4.11 (D0), U5.4 (GP2), U6.11 (D0), U7.11 (D0), U8.11 (D0), U9.11 (D0)
DISP_D1: U1.12 (D1), U2.12 (D1), U3.12 (D1), U4.12 (D1), U5.5 (GP3), U6.12 (D1), U7.12 (D1), U8.12 (D1), U9.12 (D1)
DISP_D2: U1.13 (D2), U2.13 (D2), U3.13 (D2), U4.13 (D2), U5.6 (GP4), U6.13 (D2), U7.13 (D2), U8.13 (D2), U9.13 (D2)
DISP_D3: U1.14 (D3), U2.14 (D3), U3.14 (D3), U4.14 (D3), U5.7 (GP5), U6.14 (D3), U7.14 (D3), U8.14 (D3), U9.14 (D3)
DISP_D4: U1.17 (D4), U2.17 (D4), U3.17 (D4), U4.17 (D4), U5.9 (GP6), U6.17 (D4), U7.17 (D4), U8.17 (D4), U9.17 (D4)
DISP_D5: U1.16 (D5), U2.16 (D5), U3.16 (D5), U4.16 (D5), U5.10 (GP7), U6.16 (D5), U7.16 (D5), U8.16 (D5), U9.16 (D5)
DISP_D6: U1.15 (D6), U2.15 (D6), U3.15 (D6), U4.15 (D6), U5.11 (GP8), U6.15 (D6), U7.15 (D6), U8.15 (D6), U9.15 (D6)
DISP_WR: U1.6 (WR), U2.6 (WR), U3.6 (WR), U4.6 (WR), U5.19 (GP14), U6.6 (WR), U7.6 (WR), U8.6 (WR), U9.6 (WR)
GND: J1.1, U1.10 (GND), U2.10 (GND), U3.10 (GND), U4.10 (GND), U5.3 (GND), U5.8 (GND), U5.13 (GND), U5.18 (GND), U5.23 (GND), U5.28 (GND), U5.33 (GND), U5.38 (GND), U5.42 (GND), U5.44 (GND), U5.47 (GND), U5.48 (GND), U5.49 (GND), U5.50 (GND), U6.10 (GND), U7.10 (GND), U8.10 (GND), U9.10 (GND)
PICO_UART_RX: J2.1, U5.2 (GP1)
PICO_UART_TX: J2.2, U5.1 (GP0)
VSYS: J1.2, U1.9 (VCC), U2.9 (VCC), U3.9 (VCC), U4.9 (VCC), U5.39 (VSYS), U5.40 (VBUS), U6.9 (VCC), U7.9 (VCC), U8.9 (VCC), U9.9 (VCC)

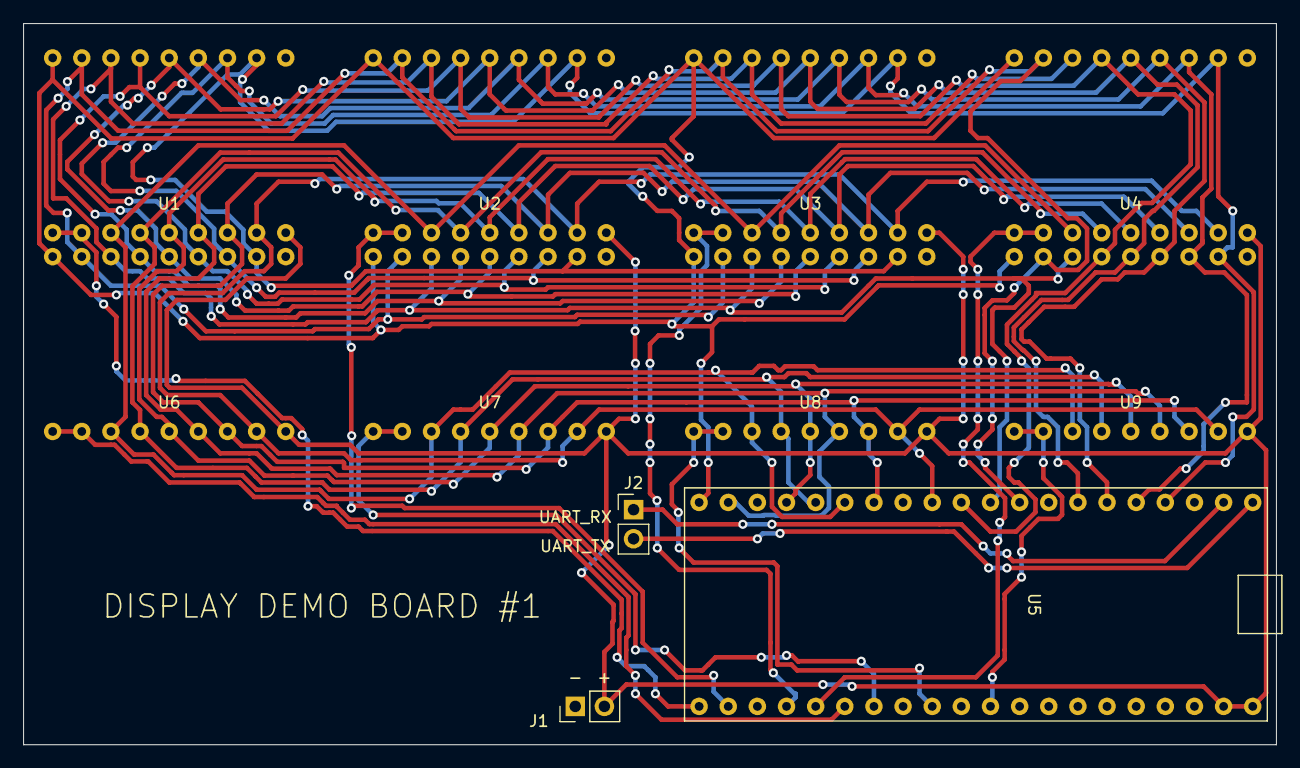
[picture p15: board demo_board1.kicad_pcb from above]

Board: 2 copper layers, 109.2 x 62.9 mm, 11 parts (0 on the bottom side), 26 nets.

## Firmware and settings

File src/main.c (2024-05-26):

#include <pico/stdlib.h>
#include <hardware/timer.h>
#include <hardware/adc.h>
#include <hardware/rtc.h>
#include <FreeRTOS.h>
#include <task.h>
#include <stdio.h>

#include "display.h"
#include "buzzer.h"
#include "knob.h"
#include "buttons.h"
#include "usb_serial.h"
#include "if_uart.h"
#include "command.h"

#define SW_MAJOR_VERSION 0
#define SW_MINOR_VERSION 501

#define MAIN_TASK_PRIORITY  1

static TaskHandle_t main_task_handle = NULL;


static void printout_sys_stats(void)
{
    static TaskStatus_t tstats[20] = {0};
    uint32_t total_rt;
    uint8_t num, i;
    float prc;

    num = uxTaskGetSystemState(tstats, sizeof(tstats), &total_rt);

    printf("\n\n\n");
    printf("Task name       | Proc time %% | Stack HWM\n");
    printf("-----------------------------------------\n");

    for (i = 0; i < num; i++)
    {
        prc = (float)tstats[i].ulRunTimeCounter / (float)total_rt * 100.0f;

        printf("%-16s|%12.2f%%|%10u\n",
               tstats[i].pcTaskName, prc, tstats[i].usStackHighWaterMark);
    }
    printf("\n");
    
    prc = 1.0f - (float)xPortGetFreeHeapSize() / (float)configTOTAL_HEAP_SIZE;
    prc *= 100.0f;
    printf("Mem usage: %0.2f%%; %u free out of %u\n",
           prc, xPortGetFreeHeapSize(), configTOTAL_HEAP_SIZE);
}


void main_task(__unused void *params) {

    printf("\n");    
    printf("SW version: %u.%u\n", SW_MAJOR_VERSION, SW_MINOR_VERSION);

    for (;;)
    {
        vTaskDelay(50000);
        printout_sys_stats();
    }
}


int main( void )
{
    stdio_init_all();

    adc_init();

    rtc_init();

    display_driver_init();

    buzzer_init();

    knob_init();

    buttons_init();

    command_init();

    display_init();

    usb_serial_init();

    if_uart_init();

    printf("Starting FreeRTOS SMP on both cores\n");
    
    xTaskCreate(main_task,
                "main",
                1024 * 4,
                NULL,
                MAIN_TASK_PRIORITY,
                &main_task_handle);

    vTaskCoreAffinitySet(main_task_handle, 1);

    vTaskStartScheduler();

    /* Something went wrong */
    for (;;)
    {
        __breakpoint();
    }
    
    return 0;
}


void vApplicationMallocFailedHook(void)
{

    printf("malloc failure!\n");
    for (;;)
    {
        __breakpoint();
    }
}


void vApplicationStackOverflowHook(TaskHandle_t xTask,
                                   char *pcTaskName)
{
    for (;;)
    {
        __breakpoint();
    }
}


uint32_t stats_get_time(void)
{
    return time_us_32();
}

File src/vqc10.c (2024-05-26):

#include <string.h>
#include <hardware/gpio.h>
#include <hardware/pio.h>
#include <hardware/dma.h>
#include <pico/time.h>

#include "font5x7_transposed.h"

#define NDISPLAYS        10
#define NCHARS           (NDISPLAYS * 4)
#define NROWS            7
#define DISPLAY_BUF_SIZE (NROWS * NCHARS)

#define VQC_ROW_START_PIN  6
#define VQC_ROW_NUM_PINS   7
#define VQC_ROW_PINS_MASK  (((1 << VQC_ROW_NUM_PINS) - 1) << VQC_ROW_START_PIN)

#define VQC_CS_START_PIN   14
#define VQC_CS_NUM_PINS    4
#define VQC_CS_PINS_MASK   (((1 << VQC_CS_NUM_PINS) - 1) << VQC_CS_START_PIN)

#define VQC_DATA_START_PIN 19
#define VQC_DATA_NUM_PINS  5
#define VQC_DATA_PINS_MASK (((1 << VQC_DATA_NUM_PINS) - 1) << VQC_DATA_START_PIN)

#define VQC_C_E1_PIN       2    
#define VQC_C_E2_PIN       3
#define VQC_C_E3_PIN       13

#define VQC_CTRL_START_PIN 2
#define VQC_CTRL_NUM_PINS  16
#define VQC_CTRL_NC1_PIN   4
#define VQC_CTRL_NC2_PIN   5

#include "vqc10.h"
#include "vqc10.pio.h"

static struct
{
    struct
    {
        uint32_t n_chars;

        struct
        {
            uint16_t char_sel_pins;
            uint16_t char_unsel_pins;
        
        } char_ctr[NCHARS];

        uint16_t on_cycles;
        uint16_t off_cycles;
        uint16_t row_on_pins;
        uint16_t row_off_pins;

    } row_ctr[NROWS];

} disp_ctr;

static uint8_t display_buf[DISPLAY_BUF_SIZE] = {0};

static int32_t vqc_dma_data_chan = -1; 
static int32_t vqc_dma_data_ctrl_chan = -1;
static int32_t vqc_dma_dispctrl_chan = -1; 
static int32_t vqc_dma_dispctrl_ctrl_chan = -1;

static const struct 
{
    const uint8_t *data;

} dma_data_ctrl_blocks[] = \
{
    {display_buf},
    {display_buf},
};

static const struct 
{
    const uint8_t *data;

} dma_dispctrl_ctrl_blocks[] = \
{
    {(const uint8_t*)&disp_ctr},
    {(const uint8_t*)&disp_ctr},
};


static uint16_t ctrl_pins_cfg(uint8_t demux, uint8_t cs, uint8_t row)
{
    uint16_t cfg = 0;

    switch (demux)
    {
    case 1:
        cfg |= (1 << VQC_C_E2_PIN) >> VQC_CTRL_START_PIN;
        cfg |= (1 << VQC_C_E3_PIN) >> VQC_CTRL_START_PIN;        
        break;

    case 2:
        cfg |= (1 << VQC_C_E1_PIN) >> VQC_CTRL_START_PIN;
        cfg |= (1 << VQC_C_E3_PIN) >> VQC_CTRL_START_PIN;
        break;

    case 3:
        cfg |= (1 << VQC_C_E1_PIN) >> VQC_CTRL_START_PIN;
        cfg |= (1 << VQC_C_E2_PIN) >> VQC_CTRL_START_PIN;
        break;

    default:
        cfg |= (1 << VQC_C_E1_PIN) >> VQC_CTRL_START_PIN;
        cfg |= (1 << VQC_C_E2_PIN) >> VQC_CTRL_START_PIN;
        cfg |= (1 << VQC_C_E3_PIN) >> VQC_CTRL_START_PIN;
        break;
    }

    cfg |= ((cs & 0b1111) << VQC_CS_START_PIN) >> VQC_CTRL_START_PIN;

    if (row >= 7)
    {
        cfg |= (0b1111111 << VQC_ROW_START_PIN) >> VQC_CTRL_START_PIN;
    }
    else
    {
        cfg |= ((~(1 << row) & 0b1111111) << 
                            VQC_ROW_START_PIN) >> VQC_CTRL_START_PIN;
    }

    return cfg;
}

static void init_ctrl_struct(void)
{

    for (uint8_t row = 0; row < NROWS; row++)
    {
        disp_ctr.row_ctr[row].n_chars = NCHARS - 1;
        disp_ctr.row_ctr[row].on_cycles = 256;
        disp_ctr.row_ctr[row].off_cycles = 3840;
        disp_ctr.row_ctr[row].row_on_pins = ctrl_pins_cfg(0, 0, row);
        disp_ctr.row_ctr[row].row_off_pins = ctrl_pins_cfg(0, 0, 0xff);

        for (uint32_t ct = 0; ct < NCHARS; ct++)
        {
            uint8_t demux = ct / 16 + 1;
            uint8_t cs = ct % 16;

            disp_ctr.row_ctr[row].char_ctr[ct].char_sel_pins = 
                                                ctrl_pins_cfg(demux, cs, 0xff);
            disp_ctr.row_ctr[row].char_ctr[ct].char_unsel_pins = 
                                                ctrl_pins_cfg(0, 0, 0xff);
        }

    }

}


static void vqc10_init_dma(void)
{
    dma_channel_config cfg;

    vqc_dma_data_chan = dma_claim_unused_channel(true);
    vqc_dma_data_ctrl_chan = dma_claim_unused_channel(true);
    vqc_dma_dispctrl_chan = dma_claim_unused_channel(true);
    vqc_dma_dispctrl_ctrl_chan = dma_claim_unused_channel(true);


    cfg = dma_channel_get_default_config(vqc_dma_data_chan);
    channel_config_set_transfer_data_size(&cfg, DMA_SIZE_32);
    channel_config_set_read_increment(&cfg, true);
    channel_config_set_dreq(&cfg, DREQ_PIO0_TX0);
    channel_config_set_chain_to(&cfg, vqc_dma_data_ctrl_chan);

    dma_channel_configure(
        vqc_dma_data_chan,
        &cfg,
        &pio0_hw->txf[VQC10_PIO_PUSH_DATA_SM],       /* Write address */
        display_buf,                                 /* Read address */
        sizeof(display_buf) / 4,
        false                                        /* Don't start yet */
    );


    /* Another DMA channel that automatically triggers the first data channel 
       when it finishes transferring the buffer to the PIO program,
       in the similar manner as in pico-examples/dma/control_blocks/control_blocks.c
     */
    cfg = dma_channel_get_default_config(vqc_dma_data_ctrl_chan);
    channel_config_set_transfer_data_size(&cfg, DMA_SIZE_32);
    channel_config_set_read_increment(&cfg, true);
    channel_config_set_write_increment(&cfg, false);
    channel_config_set_ring(&cfg, false, 1);

    dma_channel_configure(
        vqc_dma_data_ctrl_chan,
        &cfg,
        &dma_hw->ch[vqc_dma_data_chan].al3_read_addr_trig, /* Write address */
        &dma_data_ctrl_blocks[0],                          /* Read address */
        1,
        false                                              /* Don't start yet */
    );


    cfg = dma_channel_get_default_config(vqc_dma_dispctrl_chan);
    channel_config_set_transfer_data_size(&cfg, DMA_SIZE_32);
    channel_config_set_read_increment(&cfg, true);
    channel_config_set_dreq(&cfg, DREQ_PIO0_TX1);
    channel_config_set_chain_to(&cfg, vqc_dma_dispctrl_ctrl_chan);

    dma_channel_configure(
        vqc_dma_dispctrl_chan,
        &cfg,
        &pio0_hw->txf[VQC10_PIO_CTRL_SEQ_SM],        /* Write address */
        &disp_ctr,                                   /* Read address */
        sizeof(disp_ctr) / 4,
        false                                        /* Don't start yet */
    );

    cfg = dma_channel_get_default_config(vqc_dma_dispctrl_ctrl_chan);
    channel_config_set_transfer_data_size(&cfg, DMA_SIZE_32);
    channel_config_set_read_increment(&cfg, true);
    channel_config_set_write_increment(&cfg, false);
    channel_config_set_ring(&cfg, false, 1);

    dma_channel_configure(
        vqc_dma_dispctrl_ctrl_chan,
        &cfg,
        &dma_hw->ch[vqc_dma_dispctrl_chan].al3_read_addr_trig, /* Write address */
        &dma_dispctrl_ctrl_blocks[0],                          /* Read address */
        1,
        false                                                  /* Don't start yet */
    );

    dma_start_channel_mask((1u << vqc_dma_data_ctrl_chan) | 
                           (1u << vqc_dma_dispctrl_ctrl_chan));
}
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

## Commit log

2023-01-26 basic FreeRTOS setup; http server; websocket; first version of PCB; fsdatagen.py; initial static web-files;
    [fpanel_remote_pcb.kicad_pcb, fpanel_remote_pcb.kicad_sch]
2023-03-02 +fpanel task; lwip and freertos tuning; buttons and leds do work
2023-03-05 send pc uptime and temperature to client; more lwip tweaks
2023-03-06 disconnect current client if another connects
2023-03-08 print system run time stats; reduce stack sizes
2023-03-19 drive hdsp-2112 with PIO and DMA
2023-04-02 move sources to src; add demoboard1 kicad files; update readme
    [demo_board1.kicad_pcb, demo_board1.kicad_sch, fpanel_remote_pcb.kicad_pcb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]
2023-04-09 initial work on schematics for mdl2416c display
    [vin_display_mdl2416c_x10.kicad_pcb, vin_display_mdl2416c_x10.kicad_sch]
2023-04-10 complete mdl2416c display schematics
    [displays.kicad_sch, vin_display_mdl2416c_x10.kicad_sch]
2023-04-12 assign component footprints; basic pcb layout
    [vin_display_mdl2416c_x10.kicad_pcb, vin_display_mdl2416c_x10.kicad_sch]
2023-04-17 work on pcb layout
    [vin_display_mdl2416c_x10.kicad_pcb, vin_display_mdl2416c_x10.kicad_sch]
2023-04-21 +hdsp2000 display driver
2023-04-24 mdl2416c_x10 pcb routed
    [displays.kicad_sch, vin_display_mdl2416c_x10.kicad_pcb, vin_display_mdl2416c_x10.kicad_sch]
2023-04-25 mdl2416c_x10 pcb fixes/adjustments
    [displays.kicad_sch, vin_display_mdl2416c_x10.kicad_pcb, vin_display_mdl2416c_x10.kicad_sch]
2023-05-13 minor schematic fixes
    [vin_display_mdl2416c_x10.kicad_pcb, vin_display_mdl2416c_x10.kicad_sch]
2023-05-22 10x mdl2416c display fixes; buzzer pio
    [main.c, mdl2416c.c]
2023-06-24 knob/encoder pio; usb serial
2023-06-27 add klipper firmware files
2023-07-02 attempt to adapt klipper firmware
2023-07-02 remove irrelevant stuff; abandon klipper firmware adaptation
2023-07-17 control buzzer with commands - queue and play sounds
    [command.c, command.h, hdsp2000.c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]
2023-07-17 update schematic; add pdf
    [displays.kicad_sch, vin_display_mdl2416c_x10.kicad_pcb, vin_display_mdl2416c_x10.kicad_sch]
2023-08-04 work on vin_display_hdsp2121_x6 schematics
    [displays.kicad_sch, vin_display_hdsp2112_x6.kicad_pcb, vin_display_hdsp2112_x6.kicad_sch]
2023-08-24 work on hdsp2112_x6 pcb
    [displays.kicad_sch, vin_display_hdsp2112_x6.kicad_pcb, vin_display_hdsp2112_x6.kicad_sch]
2023-10-12 minor pcb changes; add decoupling caps in mdl2416c_x10
    [displays.kicad_sch, vin_display_hdsp2112_x6.kicad_pcb, vin_display_mdl2416c_x10.kicad_pcb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]
2023-10-14 ignore kicad export files
2023-10-24 fix knob for hdsp2112_x6
    [hdsp2112.c, knob.c]
2024-01-28 add hdsp2112_x6 pdf and photo; fix encoder pins
    [knob.c, main.c]
2024-02-10 initial work on hdsp2000_x20 schematic
    [displays.kicad_sch, displays2.kicad_sch, vin_display_hdsp2000_x20.kicad_pcb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]
2024-02-17 route hdsp2000_x20 board
    [displays.kicad_sch, displays2.kicad_sch, vin_display_hdsp2000_x20.kicad_pcb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]
2024-02-19 hdsp2000_x20 pcb v1.0
    [vin_display_hdsp2000_x20.kicad_pcb]
2024-02-20 work on vqc10_x10 schematics
    [displays.kicad_sch, displays_drv.kicad_sch, vin_display_vqc10_x10.kicad_pcb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]
2024-02-21 routing vqc10_x10
    [displays.kicad_sch, displays_drv.kicad_sch, vin_display_vqc10_x10.kicad_pcb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]
2024-02-26 route vqc10_x10 board
    [displays_drv.kicad_sch, vin_display_vqc10_x10.kicad_pcb]
2024-03-03 add interface UART
2024-03-08 hdsp2000_x20 minor changes
    [vin_display_hdsp2000_x20.kicad_pcb, vin_display_hdsp2000_x20.kicad_sch]
2024-03-23 minor fixes in vqc10_x10 and hdsp2000_x20 pcb/schematics
    [displays.kicad_sch, displays_drv.kicad_sch, vin_display_hdsp2000_x20.kicad_pcb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]
2024-03-30 add vqc10 module; drive vqc10_x10 with PIO and DMA; add transposed font
